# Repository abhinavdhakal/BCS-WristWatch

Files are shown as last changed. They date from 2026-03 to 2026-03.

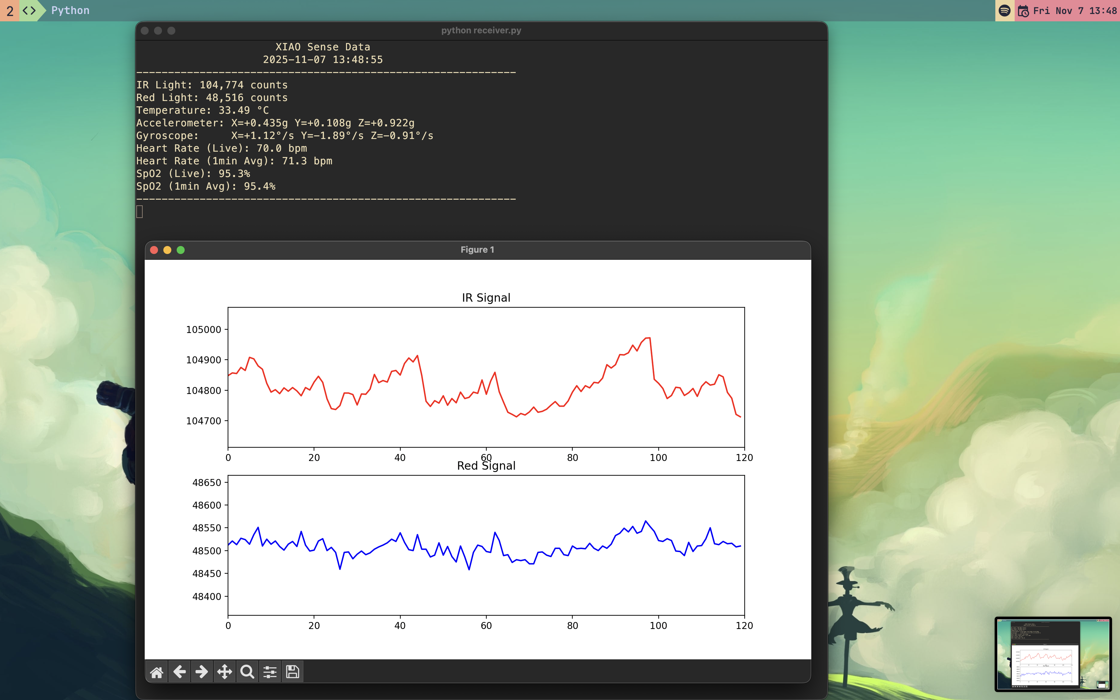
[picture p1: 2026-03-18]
SPO2, 2025-11-07 at 1.48.55 PM.png

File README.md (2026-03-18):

# WirstWatch_BCS

WirstWatch_BCS is a wearable vital-signs prototype focused on heart rate, SpO2, temperature, IMU data, and battery telemetry over BLE.

This project is still in prototype stage. The goal right now is to make the full pipeline stable end-to-end:
firmware -> BLE -> desktop receiver -> session logging -> signal processing.

## Project Structure (high level)

- `Firmware/`
  - Arduino firmware for nRF52840-based hardware
  - BLE service/characteristics, sensor sampling, battery telemetry, power modes
- `ReceiverSoftware/`
  - PyQt GUI receiver (`wirstwatch_gui.py`)
  - HR/SpO2 processing (`hr_spo2.py`)
  - BLE utility (`ble_connector.py`)
  - session CSV + log files
- `everything else/`
  - older experiments and archive material

## Current Data Pipeline

1. Firmware samples sensors and sends data over BLE.
2. Receiver GUI subscribes to BLE notifications.
3. GUI logs every session to CSV.
4. HR/SpO2 is computed from IR/Red stream in software.
5. Live values and plots are shown in the GUI.

## Firmware Data Output (data path only)

BLE Service UUID:

- `12345678-1234-1234-1234-123456789abc`

Characteristics:

- IR (`...ab1`): uint32 (4 bytes)
- Red (`...ab2`): uint32 (4 bytes)
- Temperature (`...ab3`): uint32 (4 bytes), value is `tempC * 100`
- IMU (`...ab4`): 6 x float32 (24 bytes): `ax, ay, az, gx, gy, gz`
- Battery (`...ab5`): uint32 (4 bytes), millivolts

Nominal send rates from firmware:

- IR + Red: every 20 ms (~50 Hz)
- Temperature + IMU + Battery: every 200 ms (~5 Hz)

## Receiver Software Setup

Main software folder: `ReceiverSoftware/`

### Windows (recommended for users)

- One click:
  - double-click `ReceiverSoftware/run_wirstwatch_gui.bat`

- Manual:
  - `py -3.11 -m venv .venv`
  - `.venv\Scripts\activate`
  - `pip install -r ReceiverSoftware/requirements_gui.txt`
  - `python ReceiverSoftware/wirstwatch_gui.py`

### macOS/Linux (dev)

- `python3 -m venv .venv`
- `source .venv/bin/activate`
- `pip install -r ReceiverSoftware/requirements_gui.txt`
- `python ReceiverSoftware/wirstwatch_gui.py`

## Hardware Design

### Current Design

- nRF52840-based main board with BLE
- MAX30102 (PPG) for HR/SpO2 signal source
- MLX90614 for temperature
- 6-axis IMU for motion context
- Battery measurement through onboard divider/ADC
- Wrist-worn form factor prototype

### Limitations

- This prototype uses readily available sensors, not medical-grade modules
- Wrist PPG quality is more variable than finger-based setups
- Motion artifacts are still a major challenge for stable HR/SpO2
- Current HR/SpO2 output is best-effort and for prototyping, not clinical use
- Mechanical/contact consistency is limited by prototype enclosure/fit

### Future Improvements

- Move to higher-grade optical sensor for more stable wrist PPG
- Add improved optical/mechanical design for skin contact consistency
- Upgrade HR/SpO2 algorithm (stronger motion artifact handling + confidence model)
- Add algorithm versioning/benchmarking with reference datasets
- Add calibration and validation workflow against reference device

## Notes

- Logs are written by the GUI to `ReceiverSoftware/logs/`
- Session CSV files are written to `ReceiverSoftware/sessions/`
- For software-only details, see `ReceiverSoftware/README.md`
# BCS-WristWatch

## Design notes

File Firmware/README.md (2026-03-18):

# Multi-Sensor Health Monitor

### Circuit Design Tools

EasyEDA.

### Number of Layers

2-layer PCB.

### Sensor Modules and Connections

- **MAX30102**: For heart rate and SpO₂ measurement, connected via I²C.
- **MLX90614**: For temperature sensing, connected via I²C.
- **IMU (ST LSM6DS3TR‑C)**: For motion (accelerometer and gyroscope) data, connected via I²C.

### Power Source

- **Battery Type**: 3.7V Li-ion battery.
- **Capacity**: 200mAh.

### Voltage Regulation

No voltage regulator was needed as everything was working in 3.3V and the charging circuit was already in the microcontroller itself.

### Board Size

1.19 x 1.50 inches (30.1 x 38.1 mm).

### Component Placement Logic

- **Sensors**: MAX30102 is in the backside of the PCB facing down, MLX90614 is IR based, so it is in the front side and facing down, and a cutout is made for the IR to see the skin.
- **IMU**: Integrated inside the microcontroller.

### Enclosure Design

Currently in progress, It would expose the sensors (MAX30102, MLX90614) and protect the PCB while having a strap that will put the device in constant pressure to the skin.

### Programming Environment

- **Environment**: Arduino IDE.
- **Language/Libraries**:
  - C++.
  - Libraries:
    - SparkFun MAX30105 (MAX30102) for heart rate and SpO₂ (with heartRate.h).
    - Adafruit MLX90614 for temperature.
    - SparkFun LSM6DS3 for IMU data.
    - ArduinoBLE for Bluetooth Low Energy.

### Sampling and Notification Rates

- IR & Red (MAX30102): 50 Hz (every 20 ms).
- Temperature (MLX90614): 5 Hz (every 200 ms), value sent as °C × 100.
- IMU (LSM6DS3): 5 Hz (every 200 ms), 6 floats (ax, ay, az, gx, gy, gz).
- Battery Voltage: 5 Hz (every 200 ms), value sent as millivolts.

### Data Packet Structure

**Structure:**

- IR LED: 4 bytes uint32 (raw IR count).
- Red LED: 4 bytes uint32 (raw Red count).
- Temperature: 4 bytes uint32 (object temperature °C × 100).
- IMU: 24 bytes (6 × float32: ax, ay, az, gx, gy, gz).
- Battery: 4 bytes uint32 (voltage mV).

### Transmission Protocol

- Protocol: Bluetooth Low Energy (BLE).
- Device Name: `BCS-Watch`.
- Notifications: Enabled for all characteristics listed above.
- MTU Consideration: IMU characteristic requires MTU ≥ 27 bytes for single-frame delivery (24-byte payload + overhead).

### Synchronization Logic

Sensors are read sequentially (temperature → MAX30102 → IMU) in a single pass per send interval.

### Buffering

No transmission buffering. An internal 50-sample circular buffer is used only for SpO₂ computation (not for BLE queuing).

### Receiver Setup

There is a python script to receive the data from the custom service/characteristics.

Host processing:

- HR & SpO₂ derived every ~0.5 s from rolling IR/Red buffers (`compute_hr_spo2`).
- 120-sample circular buffers (~2.5 s at 50 Hz) drive real-time plots of IR and Red.
- Battery percentage computed from linear mapping of voltage (3.0–4.2 V).

Dependencies: `bleak`, `numpy`, `matplotlib`, `scipy`.

### Error Handling

- **Mechanisms**:
  - Sensor initialization errors are logged ("Warning: Some sensors failed to initialize").
  - No explicit retry mechanism for lost BLE packets or invalid data is mentioned.

### Power Management

- **Implementation**:
  - Power state is monitored via `POWER_SENSE_PIN`.
  - Sleep modes are planned but not implemented (TODO comments for deep sleep and wake-up logic).
  - Sensors are powered down when the system is off (`sensors.shutdown()`).

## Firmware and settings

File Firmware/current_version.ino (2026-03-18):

#include <Wire.h>
#include <ArduinoBLE.h>
#include "MAX30105.h"
#include "Adafruit_MLX90614.h"
#include "LSM6DS3.h"
#include "nrf.h"
#include "nrf_power.h"
#include "nrf_gpio.h"

#define SWITCH_PIN D10
#define LED_PIN LED_BUILTIN
#include "nrf_saadc.h"

// Pin definitions
#define VBAT_ENABLE_PIN 14             // P0.14, must be LOW to enable divider
const float VREF = 3.3;                // Reference voltage
const float DIVIDER_RATIO = 2.96;      // Built-in resistor divider
const float BATTERY_CAL_FACTOR = 1.00; // Start at 1.00, tune gently with multimeter
const int BATTERY_SAMPLES = 16;
const float BATTERY_MIN_VALID_V = 2.5;
const float BATTERY_MAX_VALID_V = 4.5;
const char *BLE_DEVICE_NAME = "BCS";
const uint32_t DEVICE_SLEEP_MARKER = 0xFFFFFFFF;

float readBatteryVoltage()
{
    static float lastGoodVoltage = 3.7;

    uint32_t sum = 0;
    for (int i = 0; i < BATTERY_SAMPLES; i++)
    {
        sum += analogRead(PIN_VBAT);
        delayMicroseconds(250);
    }

    float raw = sum / (float)BATTERY_SAMPLES; // 12-bit ADC (0-4095)
    float v_pin = (raw / 4095.0f) * VREF;
    float voltage = v_pin * DIVIDER_RATIO * BATTERY_CAL_FACTOR;

    if (voltage < BATTERY_MIN_VALID_V || voltage > BATTERY_MAX_VALID_V)
        return lastGoodVoltage;

    lastGoodVoltage = voltage;
    return voltage;
}

MAX30105 max30102;
Adafruit_MLX90614 mlx = Adafruit_MLX90614();
LSM6DS3 imu(I2C_MODE, 0x6A);

// BLE setup
BLEService sensorService("12345678-1234-1234-1234-123456789abc");
BLECharacteristic irChar("12345678-1234-1234-1234-123456789ab1", BLERead | BLENotify, 4);
BLECharacteristic redChar("12345678-1234-1234-1234-123456789ab2", BLERead | BLENotify, 4);
BLECharacteristic mlxChar("12345678-1234-1234-1234-123456789ab3", BLERead | BLENotify, 4);
BLECharacteristic imuChar("12345678-1234-1234-1234-123456789ab4", BLERead | BLENotify, 24);
BLECharacteristic battChar("12345678-1234-1234-1234-123456789ab5", BLERead | BLENotify, 4);

// Descriptors
BLEDescriptor irDesc("2901", "IR Light Sensor");
BLEDescriptor redDesc("2901", "Red Light Sensor");
BLEDescriptor mlxDesc("2901", "Temperature Sensor");
BLEDescriptor imuDesc("2901", "IMU Data (ax,ay,az,gx,gy,gz)");
BLEDescriptor battDesc("2901", "Battery Voltage");

bool sensorsInitialized = false;
bool bleInitialized = false;

// Retry sensor initialization while switch remains ON
unsigned long lastInitAttempt = 0;
const unsigned long INIT_RETRY_INTERVAL_MS = 2000;

// Timers for dual-rate updates
unsigned long lastSendIR = 0;
unsigned long lastSendOther = 0;
const int intervalIR = 20;     // 50Hz
const int intervalOther = 200; // 5Hz

// Deep sleep mode flag
volatile bool inDeepSleep = false;

bool isSwitchOn()
{
    // ON means D10 is LOW (active-low logic)
    int lowCount = 0;
    for (int i = 0; i < 5; i++)
    {
        if (digitalRead(SWITCH_PIN) == LOW)
            lowCount++;
        delay(2);
    }
    return lowCount >= 3;
}

bool initSensors()
{
    Serial.println("Initializing sensors...");
    bool maxOk = false;
    bool mlxOk = false;
    bool imuOk = false;

    if (!max30102.begin(Wire, I2C_SPEED_STANDARD))
        Serial.println("MAX30102 not found!");
    else
    {
        max30102.setup();
        maxOk = true;
    }

    if (!mlx.begin())
        Serial.println("MLX90614 not found!");
    else
        mlxOk = true;

    if (imu.begin() != 0)
        Serial.println("IMU not found!");
    else
        imuOk = true;

    sensorsInitialized = maxOk && mlxOk && imuOk;

    if (sensorsInitialized)
    {
        Serial.println("Sensors initialized");
        digitalWrite(LED_PIN, HIGH);
    }
    else
    {
        Serial.println("Sensor init incomplete, will retry...");
        digitalWrite(LED_PIN, LOW);
    }

    return sensorsInitialized;
}

void deinitSensors()
{
    Serial.println("Deinitializing sensors...");
    sensorsInitialized = false;
    digitalWrite(LED_PIN, LOW);
}

void notifyDeepSleepToCentral()
{
    if (!bleInitialized)
        return;

    uint32_t marker = DEVICE_SLEEP_MARKER;
    battChar.setValue((uint8_t *)&marker, 4);
    delay(80);
}

void configureWakeSenseLow()
{
    uint32_t gpioPin = (uint32_t)digitalPinToPinName(SWITCH_PIN);
    nrf_gpio_cfg_sense_input(gpioPin, NRF_GPIO_PIN_PULLDOWN, NRF_GPIO_PIN_SENSE_LOW);
}

// Enter deep sleep mode
void enterDeepSleep()
{
    Serial.println("Entering deep sleep mode...");
    Serial.flush(); // Ensure all serial data is sent
    delay(100);

    inDeepSleep = true;

    // Notify connected GUI right before BLE shutdown.
    notifyDeepSleepToCentral();

    // Stop BLE to save power
    BLE.end();
    bleInitialized = false;

    // Disable UART
    Serial.end();

    // Turn off LED
    digitalWrite(LED_PIN, LOW);
    pinMode(LED_PIN, INPUT);

    // Disable battery voltage divider
    digitalWrite(VBAT_ENABLE_PIN, HIGH);
    pinMode(VBAT_ENABLE_PIN, INPUT);

    // Set all unused pins to INPUT to prevent current draw
    for (int i = 0; i < 32; i++)
    {
        // Skip SWITCH_PIN as we need it for wake-up
        if (i != SWITCH_PIN)
        {
            pinMode(i, INPUT);
        }
    }

    // Small delay for peripherals to shut down
    delay(10);

    // Configure wake source for true SYSTEMOFF.
    configureWakeSenseLow();

    // Enter deepest sleep. Wake causes reset and starts from setup().
    NRF_POWER->SYSTEMOFF = 1;

    // Fallback (should never be reached)
    while (1)
        ;
}

// Exit deep sleep and resume normal operation
void exitDeepSleep()
{
    // Re-initialize Serial
    Serial.begin(115200);
    delay(100);

    Serial.println("Resuming from deep sleep...");
    inDeepSleep = false;

    // Re-enable battery voltage divider
    pinMode(VBAT_ENABLE_PIN, OUTPUT);
    digitalWrite(VBAT_ENABLE_PIN, LOW);

    // Re-enable LED
    pinMode(LED_PIN, OUTPUT);
    digitalWrite(LED_PIN, HIGH);

    // Small delay for system stabilization
    delay(100);
}

bool initBLEStack()
{
    if (bleInitialized)
        return true;

    if (!BLE.begin())
    {
        Serial.println("BLE init failed!");
        return false;
    }

    BLE.setDeviceName(BLE_DEVICE_NAME);
    BLE.setLocalName(BLE_DEVICE_NAME);

    BLE.setAdvertisedService(sensorService);
    sensorService.addCharacteristic(irChar);
    sensorService.addCharacteristic(redChar);
    sensorService.addCharacteristic(mlxChar);
    sensorService.addCharacteristic(imuChar);
    sensorService.addCharacteristic(battChar);

    irChar.addDescriptor(irDesc);
    redChar.addDescriptor(redDesc);
    mlxChar.addDescriptor(mlxDesc);
    imuChar.addDescriptor(imuDesc);
    battChar.addDescriptor(battDesc);

    BLE.addService(sensorService);

    uint32_t initialValue = 0;
    irChar.setValue((uint8_t *)&initialValue, 4);
    redChar.setValue((uint8_t *)&initialValue, 4);
    mlxChar.setValue((uint8_t *)&initialValue, 4);
    battChar.setValue((uint8_t *)&initialValue, 4);

    uint8_t initialImuData[24] = {0};
    imuChar.setValue(initialImuData, 24);

    bleInitialized = true;
    return true;
}

void startAdvertisingIfReady()
{
    if (bleInitialized && sensorsInitialized)
    {
        BLE.advertise();
        Serial.println("BLE advertising...");
    }
}

void setup()
{
    Serial.begin(115200);
    delay(1000);

    Serial.println("FW tag: current_version.ino / BLE name BCS");

    analogReadResolution(12);

    pinMode(VBAT_ENABLE_PIN, OUTPUT);
    digitalWrite(VBAT_ENABLE_PIN, LOW);

    pinMode(SWITCH_PIN, INPUT_PULLDOWN);
    pinMode(LED_PIN, OUTPUT);

    // Set battery charging current to 100mA
    pinMode(22, OUTPUT);
    digitalWrite(22, LOW);

    Serial.println("=== XIAO BLE Sensor System ===");

    bool sensorsPowered = isSwitchOn();
    if (!sensorsPowered)
    {
        Serial.println("Switch is OFF at boot -> deep sleep");
        enterDeepSleep();
        return;
    }

    if (!initBLEStack())
    {
        while (1)
            ;
    }

    initSensors();
    startAdvertisingIfReady();
}

void loop()
{
    unsigned long now = millis();

    // ===== Check power state first =====
    bool sensorsPowered = isSwitchOn();

    if (!sensorsPowered)
    {
        if (sensorsInitialized)
            deinitSensors();
        enterDeepSleep();
        return;
    }

    // Retry sensor init while switch is ON until all sensors are ready
    if (!sensorsInitialized && (now - lastInitAttempt >= INIT_RETRY_INTERVAL_MS))
    {
        lastInitAttempt = now;

        if (!bleInitialized && !initBLEStack())
        {
            Serial.println("BLE init retry failed");
            delay(300);
            return;
        }

        initSensors();
        if (sensorsInitialized)
            startAdvertisingIfReady();
    }

    if (!sensorsInitialized)
    {
        delay(100);
        return;
    }

    // ===== Handle BLE connection and data transmission =====
    BLEDevice central = BLE.central();

    if (central)
    {
        Serial.print("Connected: ");
        Serial.println(central.address());

        while (central.connected())
        {
            now = millis();

            // Re-check power state during connection
            sensorsPowered = isSwitchOn();

            if (!sensorsPowered)
            {
                deinitSensors();
                enterDeepSleep();
                return;
            }

            // ===== Send sensor data only when sensors are initialized =====
            if (sensorsInitialized)
            {
                // ----- IR & Red at 50Hz -----
                if (now - lastSendIR >= intervalIR)
                {
                    lastSendIR = now;
                    long ir = max30102.getIR();
                    long red = max30102.getRed();

                    uint32_t irValue = (uint32_t)ir;
                    uint32_t redValue = (uint32_t)red;
                    irChar.setValue((uint8_t *)&irValue, 4);
                    redChar.setValue((uint8_t *)&redValue, 4);

                    // Optional: print occasionally
                    static unsigned long lastPrintIR = 0;
                    if (now - lastPrintIR >= 200)
                    {
                        lastPrintIR = now;
                        Serial.print("IR: ");
                        Serial.print(ir);
                        Serial.print("  RED: ");
                        Serial.println(red);
                    }
                }

                // ----- Other sensors at 5Hz -----
                if (now - lastSendOther >= intervalOther)
                {
                    lastSendOther = now;

                    // Temperature
                    float objectTemp = mlx.readObjectTempC();
                    uint32_t tempValue = (uint32_t)(objectTemp * 100);
                    mlxChar.setValue((uint8_t *)&tempValue, 4);

                    // IMU
                    float ax = imu.readFloatAccelX();
                    float ay = imu.readFloatAccelY();
                    float az = imu.readFloatAccelZ();
                    float gx = imu.readFloatGyroX();
                    float gy = imu.readFloatGyroY();
                    float gz = imu.readFloatGyroZ();
                    uint8_t imuData[24];
                    memcpy(imuData, &ax, 4);
                    memcpy(imuData + 4, &ay, 4);
                    memcpy(imuData + 8, &az, 4);
                    memcpy(imuData + 12, &gx, 4);
                    memcpy(imuData + 16, &gy, 4);
                    memcpy(imuData + 20, &gz, 4);
                    imuChar.setValue(imuData, 24);

                    // Battery
                    float vbat = readBatteryVoltage();
                    uint32_t battValue = (uint32_t)(vbat * 1000);
                    battChar.setValue((uint8_t *)&battValue, 4);

                    // Optional: print occasionally
                    Serial.print("Temp: ");
                    Serial.print(objectTemp, 1);
                    Serial.print("  AX: ");
                    Serial.print(ax, 2);
                    Serial.print(" AY: ");
                    Serial.print(ay, 2);
                    Serial.print(" AZ: ");
                    Serial.print(az, 2);
                    Serial.print("  GX: ");
                    Serial.print(gx, 2);
                    Serial.print(" GY: ");
                    Serial.print(gy, 2);
                    Serial.print(" GZ: ");
                    Serial.print(gz, 2);
                    Serial.print("  Batt: ");
                    Serial.println(vbat, 2);
                }
            }
        }

        Serial.println("Central disconnected, restarting advertising...");
        startAdvertisingIfReady();
    }

    // Small delay to prevent excessive loop iterations when not connected
    delay(100);
}

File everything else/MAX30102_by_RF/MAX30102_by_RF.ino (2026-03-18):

#include <Arduino.h>
#include "max30102.h"
#include "algorithm_by_RF.h"

// Quick-test: lower thresholds for weak signals
// In algorithm_by_RF.h:
// const float min_autocorrelation_ratio = 0.5;
// const float min_pearson_correlation = 0.5;

uint32_t red_buffer[BUFFER_SIZE];
uint32_t ir_buffer[BUFFER_SIZE];

void setup() {
    Serial.begin(115200);
    delay(500);

    if (!maxim_max30102_init()) {
        Serial.println("MAX30102 init failed!");
        while (1);
    }

    Serial.println("Quick test started. Place finger on sensor.");
}

void loop() {
    float spo2, ratio, correl;
    int8_t spo2_valid, hr_valid;
    int32_t heart_rate;

    // Read BUFFER_SIZE samples
    Serial.println("Reading buffer...");
    for (uint32_t i = 0; i < BUFFER_SIZE; i++) {
        maxim_max30102_read_fifo(&red_buffer[i], &ir_buffer[i]);
        delay(2);
#ifdef DEBUG
        Serial.print("Sample "); Serial.print(i);
        Serial.print(" RED="); Serial.print(red_buffer[i]);
        Serial.print(" IR="); Serial.println(ir_buffer[i]);
#endif
    }

    // Compute HR & SpO2
    rf_heart_rate_and_oxygen_saturation(
        ir_buffer, BUFFER_SIZE, red_buffer,
        &spo2, &spo2_valid, &heart_rate, &hr_valid,
        &ratio, &correl
    );

    // Read sensor temperature
    int8_t temp_int;
    uint8_t temp_frac;
    maxim_max30102_read_temperature(&temp_int, &temp_frac);
    float temp_c = temp_int + temp_frac / 16.0;

    // Print results
    if (hr_valid && spo2_valid) {
        Serial.print("HR: "); Serial.print(heart_rate);
        Serial.print(" bpm, SpO2: "); Serial.print(spo2);
        Serial.print(" %, Temp: "); Serial.print(temp_c);
        Serial.println(" C");
    } else {
        Serial.println("Reading invalid, showing raw values:");
        for (uint32_t i = 0; i < BUFFER_SIZE; i++) {
            Serial.print("RED="); Serial.print(red_buffer[i]);
            Serial.print(" IR="); Serial.println(ir_buffer[i]);
        }
    }

    delay(2000); // 2 seconds between readings
}
